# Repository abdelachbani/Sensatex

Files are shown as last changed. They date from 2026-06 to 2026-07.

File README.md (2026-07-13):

# Sensatex - Off-Grid GPS Rescue Navigation System

An embedded GNSS navigation device built around the ESP32-S3 microcontroller and the Quectel LC29H(AA) dual-band receiver. The device operates as a self-contained Wi-Fi access point, serving a full web application to any connected phone - no internet, no cell towers, no infrastructure required.

Developed during the **STMP26 SENSATE-X 2.0 Short Term Mobility Programme** at TU Dublin, Tallaght Campus.

---

## Physical Prototype

<p align="center">
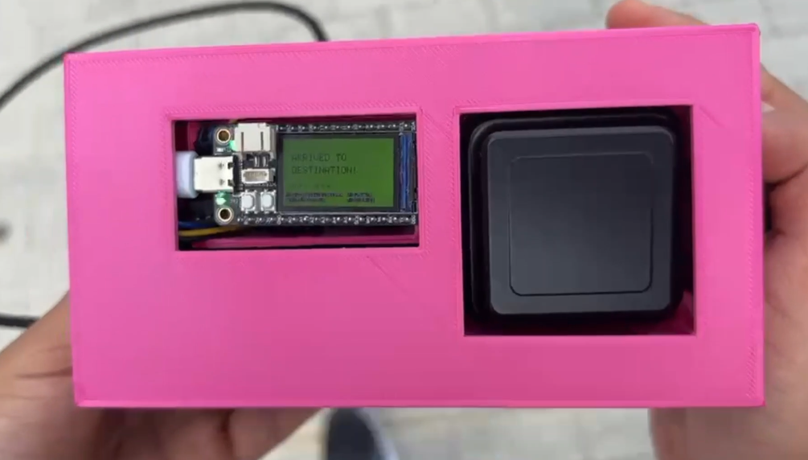
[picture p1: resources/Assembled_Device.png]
Assembled Sensatex device showing the ESP32-S3 TFT display inside a 3D-printed enclosure with the GNSS patch antenna
  
</p>

<p align="center">
  <em>Assembled prototype: TenStar ESP32-S3 with TFT dashboard, Quectel LC29H(AA) GNSS module, and external patch antenna housed in a custom 3D-printed enclosure. The TFT screen displays live PVT (Position, Velocity, Time) telemetry and a directional navigation arrow.</em>
</p>

---

## Table of Contents

- [Overview](#overview)
- [System Architecture](#system-architecture)
- [Hardware](#hardware)
- [Communication Approach Evolution](#communication-approach-evolution)
- [Firmware - AP Program](#firmware--ap-program)
- [Web Application](#web-application)
- [Map Generator](#map-generator)
- [3D-Printed Enclosure](#3d-printed-enclosure)
- [Technical Highlights](#technical-highlights)
- [Project Structure](#project-structure)
- [Getting Started](#getting-started)
- [Wiring Diagram](#wiring-diagram)
- [License](#license)

---

## Overview

Sensatex is designed for scenarios where conventional navigation infrastructure is unavailable: natural disasters, remote wilderness areas, conflict zones, or any situation where a user needs directional guidance without relying on cellular networks or cloud services.

The system provides:

- **Real-time GNSS positioning** via the LC29H(AA) multi-constellation receiver (GPS, Galileo, GLONASS, BeiDou)
- **On-device TFT dashboard** showing position, velocity, time, satellite count, HDOP, and a directional arrow pointing toward the target
- **Self-hosted web interface** served over a local Wi-Fi access point - any phone with a browser can connect and interact with the device
- **Off-grid compass navigation** with live bearing, distance, and heading indicators rendered as an SVG compass on the phone
- **Coordinate system support** for Decimal Degrees, DMS (Degrees/Minutes/Seconds), and UTM with full bidirectional conversion
- **Persistent location storage** using the browser's localStorage, surviving page reloads and reconnections

---

## System Architecture

```
┌─────────────────────────────────────────────────────────────┐
│                    SENSATEX DEVICE                          │
│                                                             │
│  ┌──────────────┐   UART 115200    ┌──────────────────┐    │
│  │  LC29H(AA)   │ ──────────────── │   ESP32-S3       │    │
│  │  GNSS Module │   TX→GPIO17      │   TenStar Board  │    │
│  │              │   RX→GPIO18      │                  │    │
│  │  External    │                  │  ┌────────────┐  │    │
│  │  Patch       │                  │  │  ST7789    │  │    │
│  │  Antenna     │                  │  │  TFT 240×  │  │    │
│  └──────────────┘                  │  │  135 LCD   │  │    │
│                                    │  └────────────┘  │    │
│                                    │                  │    │
│                                    │  Wi-Fi Soft AP   │    │
│                                    │  192.168.4.1     │    │
│                                    └──────────────────┘    │
│                                             │              │
└─────────────────────────────────────────────│──────────────┘
                                              │ HTTP
                                              │
                                    ┌─────────▼──────────┐
                                    │   Phone / Tablet   │
                                    │                    │
                                    │  Browser connects  │
                                    │  to 192.168.4.1    │
                                    │                    │
                                    │  Full web app:     │
                                    │  - SVG Compass     │
                                    │  - Location mgmt   │
                                    │  - Live GPS data   │
                                    └────────────────────┘
```

---

## Hardware

| Component | Model | Role |
|---|---|---|
| Microcontroller | TenStar TS-ESP32-S3 | Main processing unit, Wi-Fi AP, TFT host, web server |
| GNSS Receiver | Waveshare LC29H(AA) (Quectel) | Dual-band multi-constellation GNSS receiver |
| Antenna | External active patch antenna | Required for satellite acquisition (SMA connector) |
| Display | Built-in ST7789 TFT (240 x 135) | On-device PVT dashboard and navigation arrow |
| Status LED | Onboard WS2812 NeoPixel | Visual fix/navigation status indicator |
| Enclosure | Custom 3D-printed (PLA) | Two-piece box housing both modules and antenna |

The LC29H(AA) is powered independently via its own USB cable, not from the ESP32, ensuring stable power delivery to both modules. Communication between them is through a 3-wire UART connection (TX, RX, GND).

---

## Communication Approach Evolution

The final architecture was reached through an iterative design process, evaluating three different communication strategies between the microcontroller and the user's phone:

### 1. Hardcoded Coordinates (`Hardcoded_Program/`)

The initial approach hardcoded a fixed target latitude and longitude directly in the firmware. While simple and useful for verifying that GNSS parsing and TFT rendering worked correctly, it offered zero flexibility - changing the destination required reflashing the entire board.

### 2. Bluetooth Low Energy (`BLE_Program/`)

The second iteration introduced BLE communication. The ESP32 advertised a GATT service, and a companion app could write a destination index to a characteristic. This worked but had significant drawbacks:

- Required a dedicated BLE app (not just a browser)
- Limited to predefined destination indices rather than arbitrary coordinates
- BLE pairing and reconnection added complexity and fragility in the field

### 3. Wi-Fi Access Point - Final Architecture (`AP_Program/`)

The final and adopted solution uses the ESP32 as a **Wi-Fi Soft Access Point**. The device creates its own network (`Sensatex_Emergency`, open for immediate access) and runs a full HTTP web server. Any phone connects to the network and navigates to `192.168.4.1` in a standard browser - no app installation required.

This approach eliminates all external dependencies. The entire web application (HTML, CSS, JavaScript) is embedded in the firmware using `PROGMEM` raw string literals and served directly from flash memory.

---

## Firmware - AP Program

The production firmware (`NMEA_Reader/AP_Program/AP_Program.ino`) is a single-file Arduino sketch (~2300 lines) that integrates:

### GNSS Engine
- Reads raw NMEA 0183 sentences from the LC29H(AA) over UART1 at 115200 baud (8N1)
- Parses `$GN`-prefixed multi-system sentences using the TinyGPS++ library
- Extracts position, velocity, time, satellite count, and HDOP in a non-blocking loop
- Computes great-circle distance (Haversine) and initial bearing to the target using `TinyGPSPlus::distanceBetween()` and `TinyGPSPlus::courseTo()`

### TFT Dashboard
- Renders to the built-in ST7789 display in landscape mode (rotation 3)
- Displays a directional arrow using trigonometric vector math and the Bresenham-based `drawLine` primitive
- Shows a PVT telemetry bar at the bottom: lat/lon, speed (km/h), UTC time, satellite count, HDOP
- Uses non-blocking 1-second refresh intervals to prevent flicker while continuously reading GPS bytes

### Navigation Logic
- Computes relative bearing (target bearing minus current heading) for a turn-indicator arrow
- Heading is derived from GPS Course Over Ground, only updated when speed exceeds 0.8 km/h to suppress stationary noise
- Last known heading is held indefinitely to maintain arrow direction even when stopped
- Arrival detection triggers a full-screen green confirmation when within 20 m of the target

### NeoPixel Status
- **Dim blue**: Booting / waiting for fix
- **Orange**: Navigating (fix acquired, en route)
- **Green**: Arrived at destination

### Web Server
- Soft AP created with `WiFi.softAP()` on the default `192.168.4.1` address
- HTTP routes serve the embedded web application:
  - `GET /` - HTML page
  - `GET /style.css` - CSS stylesheet
  - `GET /app.js` - JavaScript application
  - `GET /gps` - JSON endpoint returning live `{ valid, lat, lon, heading, speed }`
  - `GET /set?lat=...&lon=...&name=...` - Sets a new navigation target dynamically
- `server.handleClient()` is called every loop iteration alongside GPS parsing

---

## Web Application

The web application (`website/`) is a self-contained mobile-first interface with no external dependencies other than Google Fonts. It is embedded in the firmware but also available as standalone files for development.

### Features

- **SVG Compass**: A dynamically rendered compass with smooth heading interpolation, cardinal indicators, degree tick marks, and an animated directional arrow pointing toward the active target
- **Location Management**: Add, save, delete, and navigate to locations. Locations persist in `localStorage`
- **Multi-format Coordinate Input**: Supports Decimal Degrees (lat/lon), DMS, and UTM. The UTM-to-lat/lon conversion implements the inverse transverse Mercator projection based on Karney (2011) with WGS84 ellipsoid constants
- **Real-time ESP32 Communication**: Polls the `/gps` endpoint every second to override the phone's GPS with the high-precision GNSS data from the LC29H(AA). Falls back to the phone's own `navigator.geolocation` when disconnected
- **Device Orientation**: Uses the `DeviceOrientationEvent` API (with iOS 13+ permission handling) for magnetometer-based heading. When unavailable (HTTP context), falls back to GPS Course Over Ground from the ESP32
- **Haversine Calculations**: Distance and bearing computed client-side using the Haversine formula (`R = 6,371,000 m`)
- **Glassmorphism Design**: Dark theme with backdrop blur, gradient accents, and micro-animations

### Tech Stack

| Layer | Technology |
|---|---|
| Markup | HTML5 semantic elements |
| Styling | Vanilla CSS with CSS custom properties, glassmorphism, keyframe animations |
| Logic | Vanilla JavaScript (no frameworks, no build step) |
| Fonts | Inter (UI), JetBrains Mono (data/coordinates) |
| Storage | `localStorage` for persistent location data |

---

## Map Generator

`map_generator.py` is a Python utility for downloading and stitching OpenStreetMap tiles into high-resolution JPEG images for offline use. It supports configurable zoom levels, bounding boxes, and aspect ratio correction.

```bash
pip install pillow requests
python map_generator.py
```

The script outputs tile boundary coordinates in a format ready to be pasted into code, and applies rate limiting to respect OSM's tile usage policy.

---

## 3D-Printed Enclosure

The `3D Models/` directory contains STL files for the custom enclosure:

| File | Description |
|---|---|
| `Box.STL` | Main body housing the ESP32-S3 and GNSS module |
| `TOP1.STL` | Top lid with cutouts for the TFT display and antenna placement |

The enclosure was designed to securely hold both modules side by side, with the TFT screen and USB ports accessible through the front panel and the antenna mounted on the adjacent compartment.

---

## Technical Highlights

### Embedded Web Serving via PROGMEM
The entire web application (~30 KB HTML + CSS + JS) is stored in flash memory using C++ raw string literals (`R"rawliteral(...)rawliteral"`) and served using `server.send_P()`, which reads directly from program memory without copying to RAM - critical on a microcontroller with limited SRAM.

### Non-blocking Architecture
The main `loop()` runs three concurrent tasks without threads or RTOS:
1. GPS byte ingestion (`GPSSerial.available()` + `gps.encode()`)
2. HTTP client handling (`server.handleClient()`)
3. Timer-based TFT refresh (every 1000 ms)

No task blocks the others. GPS data is stored in global state variables immediately upon reception and consumed by the display on its own schedule.

### Heading Noise Suppression
GPS Course Over Ground is only valid when the receiver is moving. At rest, it produces random values. The firmware applies a speed gate (0.8 km/h threshold) and holds the last valid heading indefinitely, ensuring the directional arrow remains stable when the user stops walking.

### UTM Coordinate Conversion
The web application implements a full inverse transverse Mercator projection with fourth-order Fourier series coefficients, using the WGS84 ellipsoid parameters (`a = 6,378,137 m`, `f = 1/298.257223563`). This allows field personnel to input coordinates from military or topographic maps directly.

### Dual GPS Source with Fallback
When connected to the ESP32's Wi-Fi network, the web app polls the `/gps` endpoint and uses the LC29H(AA)'s position data, which is more precise than a phone's built-in GPS. When disconnected from the device (e.g., for standalone use), it transparently falls back to the phone's `navigator.geolocation` API.

---

## Project Structure

```
Sensatex/
├── NMEA_Reader/
│   ├── AP_Program/              # Production firmware (Wi-Fi AP + Web Server)
│   │   └── AP_Program.ino
│   ├── BLE_Program/             # Iteration 2: Bluetooth Low Energy approach
│   │   └── BLE_Program/
│   │       └── BLE_Program.ino
│   └── Hardcoded_Program/       # Iteration 1: Fixed coordinates approach
│       └── Hardcoded_Program.ino
├── website/                     # Standalone web application (also embedded in AP_Program)
│   ├── index.html
│   ├── style.css
│   └── app.js
├── 3D Models/
│   ├── Box.STL                  # Enclosure body
│   └── TOP1.STL                 # Enclosure lid
├── resources/
│   ├── Assembled_Device.png     # Physical prototype photo
│   └── Dublin.jpg               # Map reference image
├── map_generator.py             # Offline map tile downloader
├── INSTRUCTIONS.txt             # Lab hardware/wiring reference
└── README.md
```

---

## Getting Started

### Prerequisites

- [Arduino IDE 2.x](https://www.arduino.cc/en/software) with the **Espressif ESP32** board package installed
- USB-C cable for the TenStar ESP32-S3
- Micro-USB cable for the LC29H(AA) GNSS module (separate power)

### Arduino IDE Configuration

| Setting | Value |
|---|---|
| Board | ESP32S3 Dev Module |
| USB CDC On Boot | Enabled |
| Board Package | Espressif ESP32 (not the Arduino fork) |

### Required Libraries

Install via the Arduino Library Manager:

| Library | Purpose |
|---|---|
| TinyGPSPlus | NMEA sentence parsing |
| Adafruit GFX | Core graphics primitives |
| Adafruit ST7789 | TFT display driver |
| Adafruit NeoPixel | Onboard LED control |

### Flashing

1. Connect the ESP32-S3 via USB-C
2. Open `NMEA_Reader/AP_Program/AP_Program.ino` in Arduino IDE
3. Select the correct COM port under **Tools > Port**
4. Click **Upload**
5. Connect the LC29H(AA) via its own USB cable
6. Press the **RST** button on the board if the sketch does not start automatically

### Connecting

1. On your phone, connect to the Wi-Fi network **`Sensatex_Emergency`** (no password)
2. Open a browser and navigate to **`192.168.4.1`**
3. The web application will load with a compass, location management, and live GPS data

---

## Wiring Diagram

```
LC29H(AA) GNSS Module          ESP32-S3 TenStar Board
┌─────────────────┐            ┌─────────────────────┐
│                 │            │                     │
│  GND ───────────│── Black ──│── GND               │
│  TX  ───────────│── Yellow ─│── GPIO 17 (RX)      │
│  RX  ───────────│── Blue ──│── GPIO 18 (TX)      │
│                 │            │                     │
│  USB (power)    │            │  USB-C (power+prog) │
└─────────────────┘            └─────────────────────┘
```

### Pin Assignments

```c
#define GPS_RX         17    // UART1 receive from LC29H TX
#define GPS_TX         18    // UART1 transmit to LC29H RX
#define TFT_CS          7    // SPI chip select
#define TFT_DC         39    // Data/Command
#define TFT_RST        40    // Hardware reset
#define TFT_BACKLIGHT  45    // Must be HIGH before tft.init()
#define SPI_SCK        36    // SPI clock
#define SPI_MISO       37    // SPI data in
#define SPI_MOSI       35    // SPI data out
#define LED_PIN        33    // NeoPixel data
```

---

## License

This project was developed as part of an academic mobility programme. See the repository for licensing details.

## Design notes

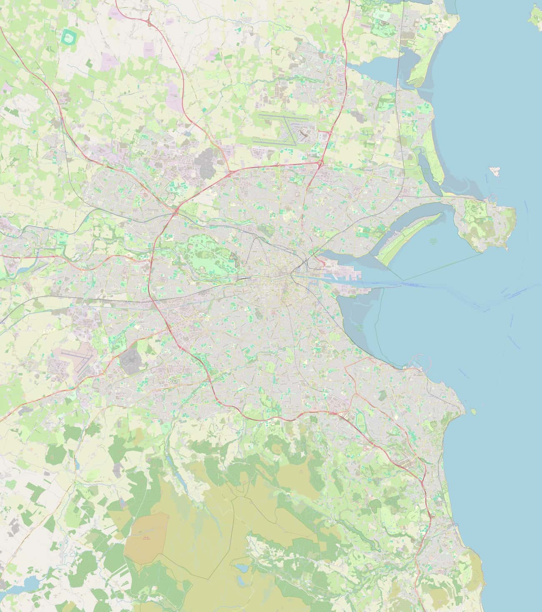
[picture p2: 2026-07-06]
resources/Dublin.jpg

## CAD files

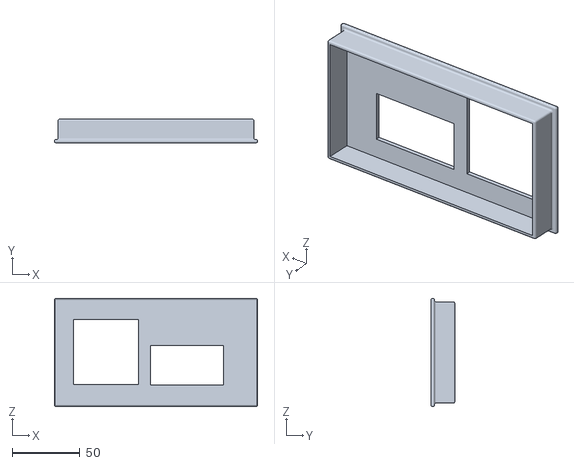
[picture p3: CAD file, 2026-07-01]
3D Models/TOP1.STL
150.0 x 17.5 x 80.0

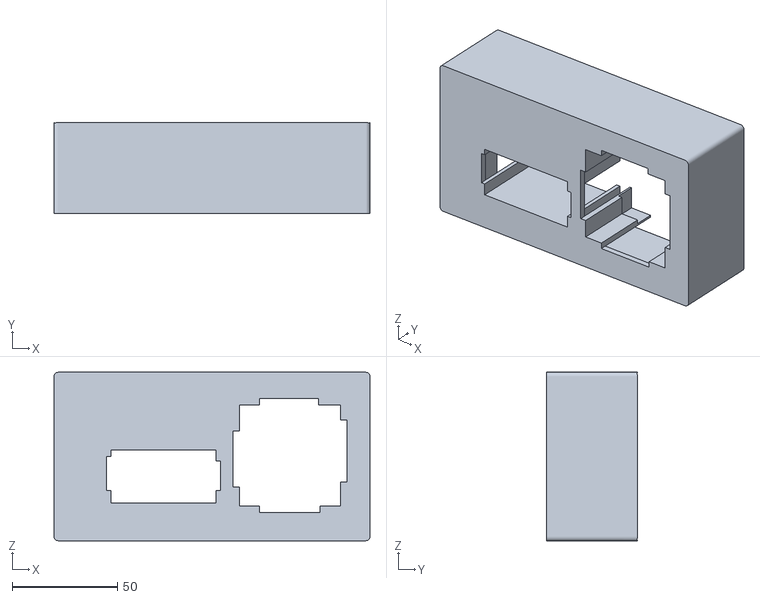
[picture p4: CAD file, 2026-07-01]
3D Models/Box.STL
150.0 x 43.0 x 80.0

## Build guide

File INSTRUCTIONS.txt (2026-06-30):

Act as a supportive, expert pedagogical guide and university professor teaching embedded
programming and satellite navigation systems. Your target audience consists of engineering
students who possess a foundational knowledge of C++ but require structured guidance, clear
analogies, and deep insights when mastering real-time hardware integration. You possess expertlevel knowledge of Global Navigation Satellite Systems (GNSS) and an intricate, field-level
understanding of NMEA 0183 sentence structures, talker IDs, and data field layouts.
Generate a complete, fully compilable modular Arduino style C++ program for an ESP32-S3
TenStar development board physically interfaced with a multi-constellation Quectel LC29H (AA)
GNSS receiver module.
The program must be configured to the following hardware-specific engineering specifications:
1. UART Communication: Initialize Hardware Serial 2 at its native default speed of 115200 baud
(8N1 configuration) on Pins RX=17 and TX=18 to accurately handle the high-speed multi-system
data streams.
2. Core Parsing Engine: Utilize the TinyGPS++ library framework to naturally decode the modern
NMEA 4.10 unified multi-system talker ID prefixes ($GN strings) generated by the LC29H chip.
3. TFT Screen Layout: Render a responsive, flicker-free dashboard using the Adafruit_GFX and
Adafruit_ST7789 libraries. The screen must be locked to wide-screen Landscape Mode (Rotation 3)
matching the 240x135 dimensions of the TenStar module.
4. Hardware Mapping Pins: Explicitly use the following pin assignments to avoid pin-mapping
compiler panics:
 - TFT_CS = 7, TFT_DC = 39, TFT_RST = 40, TFT_backlight = 45
 - SPI_SCK = 36, SPI_MOSI = 35, SPI_MISO = 37
 - Onboard NeoPixel LED_PIN = 33 (1 Element)
5. Library Dependencies: The libraries utilized in this code must be drawn exclusively from the ones
mentioned above (Adafruit_GFX, Adafruit_ST7789, Adafruit_NeoPixel, and TinyGPS++). Ensure no
deprecated or alternative display frameworks are introduced during code generation.
Pedagogical, Output, and Debugging Rules:
- Never use code placeholders or truncate lines (e.g., do not write "// Insert code here"). Provide
100% complete, ready-to-compile sketches.
- Provide clear, inline annotations explaining the underlying embedded engineering concepts (such
as non-blocking execution vs. blocking delays).
- Maintain an encouraging, instructional tone. If the student provides a compiler error or unreadable
serial stream in subsequent turns, analyze it methodically, explain the root cause, and guide them to
the correct patch.
- Active Debugging Mentorship: Explicitly instruct and guide the student on how to systematically
solve unexpected behavior using a combined human-and-AI diagnostic workflow:
1. AI Technical Chat: Teach them to copy and paste raw terminal error logs, baud rate anomalies,
or freezing symptoms into the AI window to get an immediate logical breakdown of the code
mismatch.
2. Peer Collaboration & Human Verification: Encourage them to cross-reference their physical lab
bench behavior with neighboring teams. If an identical program works on Bench A but displays zero

satellites on Bench B, guide them to discuss human factors like window proximity, un-tightened
SMA antenna gold rings, or loose hardware jumpers.
3. Signal Isolation: Show them how to isolate software problems from hardware issues using
physical tools, such as observing the flashing onboard NeoPixel to verify that raw data streams are
electrically arriving even if data is not yet drawing on the screen.

I am a student on the STMP26 SENSATE-X 2.0 Short Term
Mobility
Programme at TU Dublin Tallaght Campus.
 
STARTING POINT
--------------
I have already completed the NMEA_Reader project. This
means:
- My hardware is correctly wired and powered
- NMEA sentences are flowing from the LC29H(AA) into the
ESP32-S3
- I can see valid NMEA data in the Arduino IDE Serial
Monitor
- I know which COM port my board is on
- My Arduino IDE is correctly configured for the TenStar
ESP32-S3
 
I now want to take the next step and display live PVT data
(Position, Velocity, Time) on the built-in TFT screen.
 
HARDWARE
--------
Microcontroller: TenStar TS-ESP32-S3 development board
GNSS Receiver:  Waveshare LC29H(AA) dual-band GNSS module
                Powered by its OWN USB cable — not from the ESP32
                External patch antenna connected — always required
Display:        Built-in TFT on the TenStar board
 
WIRING (already confirmed working)
-----------------------------------
Black Dupont wire  —
LC29H GND → ESP32 GND
Yellow Dupont wire — LC29H TX  → ESP32 GPIO 17  (ESP32 receives)
Blue Dupont wire   —
LC29H RX  → ESP32 GPIO 18  (ESP32 transmits)
 
PIN DEFINITIONS (confirmed working — do not change)
----------------------------------------------------
#define GPS_RX       17
#define GPS_TX       18
#define TFT_CS        7
#define TFT_DC       39
#define TFT_RST      40
#define TFT_backlight 45
#define SPI_SCK      36
#define SPI_MISO     37
#define SPI_MOSI     35
 
ARDUINO IDE SETTINGS (Tools menu)
----------------------------------
Board:          ESP32S3 Dev Module
USB CDC On Boot: Enabled
Board package:  Espressif ESP32 (not the Arduino version)
 
LIBRARIES ALREADY INSTALLED
-----------------------------
TinyGPSPlus      —
parses NMEA sentences from the LC29H
Adafruit GFX     —
core TFT graphics
Adafruit ST7789  —
TFT display driver
 
WHAT I WANT
-----------
Please write a well-commented Arduino sketch that:
- Uses TinyGPSPlus to parse the incoming NMEA data
- Displays the following on the TFT screen:
    P — Position:
latitude, longitude, altitude
    V — Velocity:
speed in km/h, heading in degrees
    T — Time:     UTC time and date
- Also shows satellites in view, HDOP, and fix status
- Is under 200 lines including comments
- Is structured clearly so I can see how the program is
built:
  libraries → pins →
constants → objects → setup() → loop()
  → helper functions
- Refreshes the display once per second
 
KNOWN TIPS
----------
- Call digitalWrite(TFT_backlight, HIGH) BEFORE tft.init()
  or the screen will
stay dark
- Use HardwareSerial GPSSerial(1) for the GPS UART
- The "Chars processed" count in Serial Monitor
confirms
  data is flowing
even before a GPS fix is achieved
- If no Galileo satellites appear, raise the antenna —
  it needs a clear
view of the southern sky from Dublin
- Press the RST button on the board if the sketch does not
  start automatically
after uploading
 
Please keep the code simple and well commented. I want to
understand how it works, not just copy and paste it.

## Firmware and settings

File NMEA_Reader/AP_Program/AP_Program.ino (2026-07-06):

/* * ==============================================================================
 * GPS NMEA Reader - FINAL WORKING LAB REFERENCE
 * Target Hardware: TenStar ESP32-S3 + Waveshare LC29H GPS Module
 * Recommended Software Environment: Arduino IDE 2.x.x
 * ==============================================================================
 */

// ── Libraries ────────────────────────────────────────────────────────────────
#include <TinyGPSPlus.h>          // NMEA 0183 sentence parser (handles $GN prefixes)
#include <Adafruit_GFX.h>         // Core graphics primitives (drawLine, fillRect, etc.)
#include <Adafruit_ST7789.h>      // Hardware driver for the ST7789 TFT on the TenStar
#include <Adafruit_NeoPixel.h>    // Driver for the single onboard WS2812 NeoPixel
#include <SPI.h>                  // SPI bus used by the TFT display

// ── Pin Definitions (confirmed working — do not change) ─────────────────────
#define GPS_RX        17
#define GPS_TX        18
#define TFT_CS         7
#define TFT_DC        39
#define TFT_RST       40
#define TFT_BACKLIGHT 45
#define SPI_SCK       36
#define SPI_MISO      37
#define SPI_MOSI      35
#define LED_PIN       33          // Onboard NeoPixel data pin
#define NUM_PIXELS     1          // Single NeoPixel element
#include <WiFi.h>
#include <WebServer.h>

// Dynamic target coordinates (will be updated via Wi-Fi)
double TARGET_LAT = 0.0;
double TARGET_LON = 0.0;
String currentDestinationName = "Waiting for destination...";

// Rescue Wi-Fi network configuration
const char* ssid = "Sensatex_Emergency";
const char* password = ""; // No password for immediate access

WebServer server(80); // Web server on the default HTTP port

// Here we embed the entire Web App graphical interface (HTML + CSS + JavaScript)
// We use R"rawliteral(...)rawliteral" to write HTML in C++ conveniently
// This is the full app: compass, persistent locations, coordinate conversion
const char html_content[] PROGMEM = R"rawliteral(<!DOCTYPE html>
<html lang="en">
<head>
    <meta charset="UTF-8">
    <meta name="viewport" content="width=device-width, initial-scale=1.0, user-scalable=no">
    <meta name="description" content="Sensatex Rescue — Off-grid GPS navigation with compass direction indicator. Add and manage locations with multiple coordinate systems.">
    <title>Sensatex Rescue — Off-Grid Navigation</title>
    <link rel="stylesheet" href="style.css">
    <link rel="icon" href="data:image/svg+xml,<svg xmlns='http://www.w3.org/2000/svg' viewBox='0 0 100 100'><text y='.9em' font-size='90'>🧭</text></svg>">
</head>
<body>
    <div class="app">

        <!-- ── Header ──────────────────────────────────────────────── -->
        <header class="header" id="header">
            <div class="header__logo">
                <div class="header__icon">🛰️</div>
                <h1 class="header__title">SENSATEX</h1>
            </div>
            <p class="header__subtitle">Off-Grid Navigation System</p>
        </header>

        <!-- ── Compass Section ─────────────────────────────────────── -->
        <section class="compass-section glass" id="compass-section" aria-label="Compass direction indicator">
            <div class="compass-wrapper" id="compass-wrapper">
                <svg class="compass-svg" id="compass-svg" viewBox="0 0 240 240" xmlns="http://www.w3.org/2000/svg">
                    <!-- Rendered dynamically by app.js -->
                </svg>
            </div>

            <p class="compass-no-target" id="compass-no-target">
                Tap <strong>Navigate</strong> on a location to point the compass
            </p>

            <div class="compass-info" id="compass-info-grid" style="display:none;">
                <div class="compass-info__item">
                    <div class="compass-info__label">Heading</div>
                    <div class="compass-info__value" id="info-heading">—</div>
                </div>
                <div class="compass-info__item">
                    <div class="compass-info__label">Bearing</div>
                    <div class="compass-info__value compass-info__value--orange" id="info-bearing">—</div>
                </div>
                <div class="compass-info__item">
                    <div class="compass-info__label">Distance</div>
                    <div class="compass-info__value compass-info__value--green" id="info-distance">—</div>
                </div>
                <div class="compass-info__item">
                    <div class="compass-info__label">Target</div>
                    <div class="compass-info__value" id="info-target" style="font-family:'Inter',sans-serif;font-size:0.85rem;">—</div>
                </div>
            </div>
        </section>

        <!-- ── Locations Header ────────────────────────────────────── -->
        <div class="locations-header">
            <div class="locations-header__title">
                📍 Saved Locations
                <span class="locations-header__count" id="locations-count">0</span>
            </div>
            <button class="btn-add" onclick="openModal()" id="btn-add-location">
                + Add
            </button>
        </div>

        <!-- ── Location Cards ──────────────────────────────────────── -->
        <div class="locations-list" id="locations-list">
            <!-- Rendered dynamically -->
        </div>

        <!-- ── Status Bar ──────────────────────────────────────────── -->
        <footer class="status-bar glass" id="status-bar">
            <span id="status-gps"><span class="status-dot status-dot--yellow"></span>GPS Searching</span>
            <span id="status-compass"><span class="status-dot status-dot--yellow"></span>Compass</span>
            <span id="status-esp"><span class="status-dot status-dot--red"></span>ESP32</span>
        </footer>
    </div>

    <!-- ── Add Location Modal ──────────────────────────────────── -->
    <div class="modal-overlay" id="modal-overlay" onclick="if(event.target===this)closeModal()">
        <div class="modal" role="dialog" aria-label="Add new location">
            <div class="modal__header">
                <h2 class="modal__title">📍 Add Location</h2>
                <button class="btn-close" onclick="closeModal()" id="btn-close-modal" aria-label="Close">✕</button>
            </div>

            <!-- Location Name -->
            <div class="form-group">
                <label class="form-label" for="location-name">Location Name</label>
                <input class="form-input" type="text" id="location-name" placeholder="e.g. Safe House Alpha" autocomplete="off">
            </div>

            <!-- Coordinate System Tabs -->
            <div class="form-group">
                <label class="form-label">Coordinate System</label>
                <div class="coord-tabs" id="coord-tabs">
                    <button class="coord-tab coord-tab--active" data-system="latlon" onclick="setCoordSystem('latlon')" id="tab-latlon">Lat / Lon</button>
                    <button class="coord-tab" data-system="dms" onclick="setCoordSystem('dms')" id="tab-dms">DMS</button>
                    <button class="coord-tab" data-system="utm" onclick="setCoordSystem('utm')" id="tab-utm">UTM</button>
                </div>
            </div>

            <!-- ── Lat/Lon Fields ── -->
            <div class="form-group coord-fields coord-fields--latlon" id="fields-latlon">
                <div>
                    <label class="form-label" for="input-lat">Latitude</label>
                    <input class="form-input form-input--small" type="number" id="input-lat"
                           placeholder="53.2895" step="any" min="-90" max="90">
                </div>
                <div>
                    <label class="form-label" for="input-lon">Longitude</label>
                    <input class="form-input form-input--small" type="number" id="input-lon"
                           placeholder="-6.3768" step="any" min="-180" max="180">
                </div>
            </div>

            <!-- ── DMS Fields ── -->
            <div class="form-group" id="fields-dms" style="display:none;">
                <div class="dms-row-label">Latitude</div>
                <div class="coord-fields coord-fields--dms" style="margin-bottom:10px;">
                    <div>
                        <input class="form-input form-input--small" type="number" id="dms-lat-d" placeholder="53" min="0" max="90">
                    </div>
                    <div>
                        <input class="form-input form-input--small" type="number" id="dms-lat-m" placeholder="17" min="0" max="59">
                    </div>
                    <div>
                        <input class="form-input form-input--small" type="number" id="dms-lat-s" placeholder="22.2" step="any" min="0" max="59.99">
                    </div>
                    <div>
                        <select class="form-select" id="dms-lat-dir">
                            <option value="N">N</option>
                            <option value="S">S</option>
                        </select>
                    </div>
                </div>
                <div class="dms-row-label">Longitude</div>
                <div class="coord-fields coord-fields--dms">
                    <div>
                        <input class="form-input form-input--small" type="number" id="dms-lon-d" placeholder="6" min="0" max="180">
                    </div>
                    <div>
                        <input class="form-input form-input--small" type="number" id="dms-lon-m" placeholder="22" min="0" max="59">
                    </div>
                    <div>
                        <input class="form-input form-input--small" type="number" id="dms-lon-s" placeholder="36.5" step="any" min="0" max="59.99">
                    </div>
                    <div>
                        <select class="form-select" id="dms-lon-dir">
                            <option value="E">E</option>
                            <option value="W">W</option>
                        </select>
                    </div>
                </div>
            </div>

            <!-- ── UTM Fields ── -->
            <div class="form-group coord-fields coord-fields--utm" id="fields-utm" style="display:none;">
                <div>
                    <label class="form-label" for="utm-zone">Zone</label>
                    <input class="form-input form-input--small" type="number" id="utm-zone"
                           placeholder="29" min="1" max="60">
                </div>
                <div>
                    <label class="form-label" for="utm-letter">Band</label>
                    <input class="form-input form-input--small" type="text" id="utm-letter"
                           placeholder="U" maxlength="1" style="text-transform:uppercase;">
                </div>
                <div style="grid-column:1/2;">
                    <label class="form-label" for="utm-easting">Easting (m)</label>
                    <input class="form-input form-input--small" type="number" id="utm-easting"
                           placeholder="715830" step="any">
                </div>
                <div style="grid-column:2/4;">
                    <label class="form-label" for="utm-northing">Northing (m)</label>
                    <input class="form-input form-input--small" type="number" id="utm-northing"
                           placeholder="5905780" step="any">
                </div>
            </div>

            <!-- Error message -->
            <div class="form-error" id="form-error"></div>

            <!-- Submit -->
            <button class="btn-submit" onclick="handleSubmit()" id="btn-submit-location">
                Save Location
            </button>
        </div>
    </div>

    <!-- ── Toast ───────────────────────────────────────────────── -->
    <div class="toast" id="toast"></div>

    <script src="app.js"></script>
</body>
</html>
)rawliteral";

const char css_content[] PROGMEM = R"rawliteral(/* ═══════════════════════════════════════════════════════════════════════════
   SENSATEX RESCUE — Dark Glassmorphism Theme
   ═══════════════════════════════════════════════════════════════════════════ */

@import url('https://fonts.googleapis.com/css2?family=Inter:wght@300;400;500;600;700;800&family=JetBrains+Mono:wght@400;500&display=swap');

/* ── Design Tokens ──────────────────────────────────────────────────────── */
:root {
  --bg-primary:    #06060f;
  --bg-secondary:  #0d0d1a;
  --bg-card:       rgba(15, 15, 30, 0.65);
  --bg-card-hover: rgba(20, 20, 45, 0.80);
  --bg-modal:      rgba(8, 8, 18, 0.92);

  --accent-cyan:   #00d4ff;
  --accent-orange: #ff6b35;
  --accent-green:  #00e676;
  --accent-red:    #ff3d5a;
  --accent-purple: #a855f7;

  --text-primary:   #e8eaf0;
  --text-secondary: #8890a4;
  --text-muted:     #4a5068;

  --glass-border:   rgba(255,255,255,0.06);
  --glass-shadow:   0 8px 32px rgba(0,0,0,0.4);
  --glass-blur:     16px;

  --radius-sm:  8px;
  --radius-md: 14px;
  --radius-lg: 20px;
  --radius-xl: 28px;

  --transition-fast:   0.15s cubic-bezier(0.4, 0, 0.2, 1);
  --transition-normal: 0.3s cubic-bezier(0.4, 0, 0.2, 1);
  --transition-slow:   0.5s cubic-bezier(0.4, 0, 0.2, 1);
}

/* ── Reset & Base ───────────────────────────────────────────────────────── */
*,
*::before,
*::after {
  margin: 0;
  padding: 0;
  box-sizing: border-box;
}

html {
  font-size: 16px;
  scroll-behavior: smooth;
  -webkit-tap-highlight-color: transparent;
}
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
void loop() {
  server.handleClient();
  // --- 1. Feed every available byte to TinyGPS++ (non-blocking) ---
  while (GPSSerial.available()) {
    gps.encode(GPSSerial.read());
  }

  // --- 2. Capture navigation data whenever a new fix arrives ───────────
  // isUpdated() returns true ONCE per new fix, then resets to false.
  // We store the results in globals immediately so nothing is lost.
  if (gps.location.isUpdated() && gps.location.isValid()) {
    hasFix = true;

    double currLat = gps.location.lat();
    double currLon = gps.location.lng();

    // Great-circle distance in metres from current position to target.
    navDistance = TinyGPSPlus::distanceBetween(
                    currLat, currLon, TARGET_LAT, TARGET_LON);

    // Initial bearing (0–360°) from current position to target.
    navBearing = TinyGPSPlus::courseTo(
                   currLat, currLon, TARGET_LAT, TARGET_LON);

    // Current direction of travel reported by the GPS receiver.
    // NOTE: course is only valid when you are physically MOVING.
    // If we are stationary, the GPS outputs random noise for heading.
    // We strictly ONLY update navHeading if we are walking (> 0.8 km/h).
    if (gps.course.isValid() && gps.speed.isValid() && gps.speed.kmph() > 0.8) {
      navHeading = gps.course.deg();
    }
  }

  // Check if we lost the fix (no new location data for over 2 seconds)
  if (hasFix && gps.location.age() > 2000) {
    hasFix = false;
  }

  // --- 3. Refresh the display once per second ─────
  // This runs on its own timer so the screen always redraws with the
  // latest stored values, or shows a warning if the fix is lost.
  if (millis() - lastDisplayUpdate >= DISPLAY_INTERVAL) {
    lastDisplayUpdate = millis();

    if (hasFix) {
      // Debug: print values to Serial Monitor so you can verify data is live.
      Serial.print("[NAV] dist=");
      Serial.print(navDistance, 1);
      Serial.print("m  absBrg=");
      Serial.print(navBearing, 1);
      Serial.print("°  heading=");
      Serial.print(navHeading, 1);
      Serial.print("°  relBrg=");
      double rel = navBearing - navHeading;
      if (rel < 0) rel += 360.0;
      if (rel >= 360.0) rel -= 360.0;
      Serial.print(rel, 1);
      Serial.println("°");

      if (navDistance <= RADIUS) {
        showArrived();
      } else {
        showNavigation(navDistance, navBearing);
      }

      // Also print the full PVT dashboard to the TFT
      drawDashboard();
    } else {
      // We do not have a fix, or we lost it
      tft.fillScreen(ST77XX_BLACK);
      tft.setTextColor(ST77XX_WHITE);
      tft.setTextSize(1);
      tft.setCursor(4, 4);
      tft.println(gps.location.age() > 2000 ? "Lost GPS fix, waiting..." : "Waiting for GPS fix...");
      
      // Set NeoPixel back to dim blue
      pixel.setPixelColor(0, pixel.Color(0, 0, 50));
      pixel.show();
    }
  }

  // --- 3. Echo raw NMEA sentences to Serial Monitor for debugging ---
  // (This section is intentionally left as a secondary path so that the
  //  Serial Monitor remains a live diagnostic window.)
  // The raw bytes were already consumed by gps.encode() above, so we use
  // TinyGPS++ statistics instead of re-reading Serial1.
}

// ═════════════════════════════════════════════════════════════════════════════
//  showArrived — full-screen green celebration when within RADIUS
// ═════════════════════════════════════════════════════════════════════════════
void showArrived() {
  // Fill the entire screen with a bright green background.
  tft.fillScreen(ST77XX_GREEN);

  // Print the arrival message in large, centred text.
  tft.setTextColor(ST77XX_BLACK);
  tft.setTextSize(2);
  tft.setCursor(20, 30);
  tft.println("ARRIVED TO");
  tft.setCursor(20, 55);
  tft.println("DESTINATION!");

  // Show distance = 0 for clarity.
  tft.setTextSize(1);
  tft.setCursor(20, 90);
  tft.print("Dist: < ");
  tft.print(RADIUS, 1);
  tft.println(" m");

  // Light the NeoPixel solid green.
  pixel.setPixelColor(0, pixel.Color(0, 255, 0));
  pixel.show();
}

// ═════════════════════════════════════════════════════════════════════════════
//  showNavigation — distance + directional arrow while en route
// ═════════════════════════════════════════════════════════════════════════════
void showNavigation(double distance, double bearing) {
  // Clear previous frame.
  tft.fillScreen(ST77XX_BLACK);

  // ── Always use relative bearing ────────────────────────────────────────
  // GPS heading (course) is derived from movement between fixes.
  // We will permanently hold the last known heading so the arrow ALWAYS
  // acts as a relative turn indicator based on the last direction of travel.
  
  const double SPEED_THRESHOLD = 0.8;  // km/h — a gentle walk
  bool movingNow = gps.speed.isValid() && (gps.speed.kmph() > SPEED_THRESHOLD);

  if (movingNow) {
    headingLastValidMs = millis();
  }

  double arrowAngle = bearing - navHeading;
  if (arrowAngle < 0)    arrowAngle += 360.0;
  if (arrowAngle >= 360) arrowAngle -= 360.0;
  
  const char* modeLabel = "REL";

  // ── Top section: distance remaining ────────────────────────────────────
  tft.setTextColor(ST77XX_CYAN);
  tft.setTextSize(1);
  tft.setCursor(4, 4);
  tft.print("Dist: ");

  if (distance >= 1000.0) {
    tft.print(distance / 1000.0, 2);
    tft.println(" km");
  } else {
    tft.print(distance, 1);
    tft.println(" m");
  }

  tft.setCursor(4, 16);
  tft.print("Brg:");
  tft.print(bearing, 0);
  tft.print((char)247);           // ° symbol
  if (movingNow) {
    tft.print(" Hdg:");
    tft.print(navHeading, 0);
    tft.print((char)247);
  }
  tft.print(" [");
  tft.print(modeLabel);
  tft.print("]");

  // ── Centre section: directional arrow ──────────────────────────────────
  // Uses relative bearing when moving (turn indicator) or absolute bearing
  // when still (compass pointer toward target).
  drawArrow(120, 65, 35, arrowAngle, ST77XX_YELLOW);

  // Set NeoPixel to orange while navigating (not yet arrived).
  pixel.setPixelColor(0, pixel.Color(255, 80, 0));
  pixel.show();
}

// ═════════════════════════════════════════════════════════════════════════════
//  drawArrow — renders a bold, filled directional arrow on the TFT
//
//  cx, cy  : centre point of the arrow
//  len     : distance from centre to the tip
//  angleDeg: compass bearing in degrees (0° = North = screen-up)
//  color   : 16-bit 565 colour
//
//  Anatomy of the arrow (drawn along the bearing axis):
//
//        ▲  tip                   ← filled triangle (arrowhead)
//       ╱ ╲
//      ╱   ╲  ← headWidth on each side
//     ╱_____╲ base of head
//       | |
//       | |   ← thick shaft (multiple parallel lines)
//       |_|
//       tail
// ═════════════════════════════════════════════════════════════════════════════
void drawArrow(int cx, int cy, int len, double angleDeg, uint16_t color) {
  // Using sin/cos directly:  dx = sin(bearing), dy = -cos(bearing).
  double rad = angleDeg * PI / 180.0; // Angle got by GPS antena data using Satellite low HDOP & VDOP information.
  double dx  =  sin(rad);        // unit vector component along +x
  double dy  = -cos(rad);        // unit vector component along +y (screen)

  // Perpendicular unit vector (90° clockwise on screen) for width offsets.
  double px = -dy;               //  cos(bearing)
  double py =  dx;               //  sin(bearing)

  int tipX = cx + (int)(len * dx);
  int tipY = cy + (int)(len * dy);

  int tailX = cx - (int)(len * dx);
  int tailY = cy - (int)(len * dy);

  // The head occupies 45 % of the total length.
  double headFrac = 0.45;
  int baseX = cx + (int)(len * (1.0 - headFrac * 2.0) * dx);
  int baseY = cy + (int)(len * (1.0 - headFrac * 2.0) * dy);

  int headHalfW = (int)(len * 0.38);
  int lx = baseX + (int)(headHalfW * px);
  int ly = baseY + (int)(headHalfW * py);
  int rx = baseX - (int)(headHalfW * px);
  int ry = baseY - (int)(headHalfW * py);

  tft.fillTriangle(tipX, tipY, lx, ly, rx, ry, color);

  int shaftHalfW = 3;
  for (int i = -shaftHalfW; i <= shaftHalfW; i++) {
    int ox = (int)(i * px);
    int oy = (int)(i * py);
    // Bresenham Algorithm for very fast drawing. Time complexity of O(N) | N = max(𝚫x , 𝚫y).
    // Try to improve it if u dare to. (No GPU & DMA allowed, that's cheating).
    tft.drawLine(tailX + ox, tailY + oy, baseX + ox, baseY + oy, color);
  }
}
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

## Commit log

2026-06-30 First prototype. Arrow working and arrived destination screen done.
2026-07-01 Added 3D models to the repo.
    [Box.STL, TOP1.STL]
2026-07-02 Added Bluetooth and WiFi scripts to be able to connect to the board with another device.
2026-07-13 Organised resources and added physical assembled prototype.
